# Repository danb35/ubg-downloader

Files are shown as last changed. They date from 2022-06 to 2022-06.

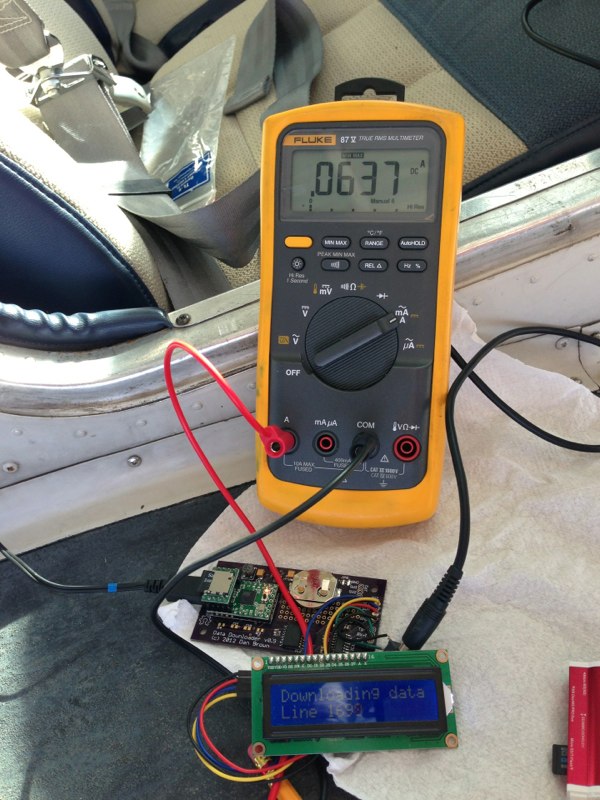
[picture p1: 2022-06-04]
Pictures/IMG_0427.jpg

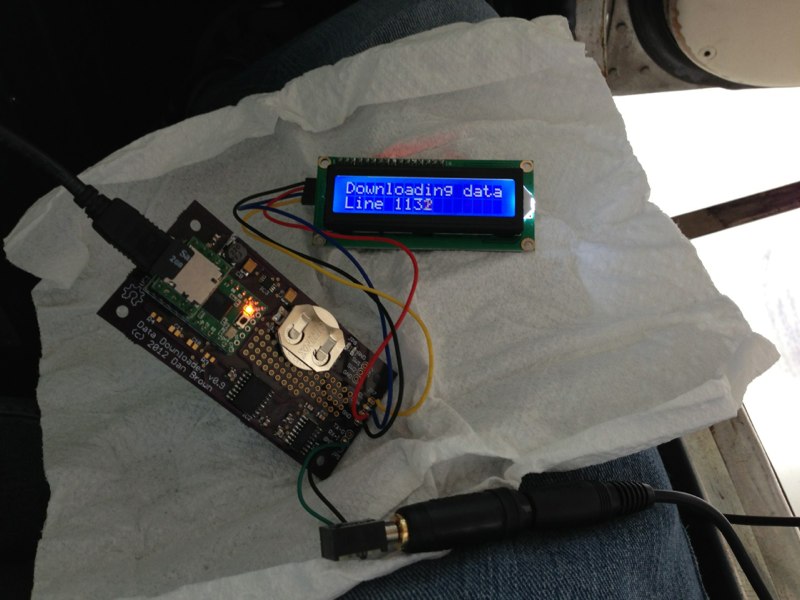
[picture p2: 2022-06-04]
Pictures/IMG_0401.jpg

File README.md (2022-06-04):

# ubg-downloader
Device to download data from EI UBG-16/MUX-8A

# Introduction
This device developed out of a desire to download data from the [Electronics International](https://www.iflyei.com/) [UBG-16](https://www.iflyei.com/product/ubg-16-ultimate-bar-graph/) in my Mooney aircraft.  EI provide (at an extra cost) a serial cable and software you can install on your laptop, but I didn't want to need to drag a laptop out to the plane to download data; I wanted a small, battery-operated device that would download the data onto an SD card.  This device will do that.

# Status
This project is *archived.*  I no longer have the airplane or any of the EI hardware to test with.  The software and hardware documentation are provided here for anyone to use, and to build on if desired, but I won't be able to provide much in the way of support.  Primary development took place in 2012, so my memory may not be too clear about the details.

But with that said, it worked.  Once the clock was set (I never did get around to developing a UI to do that through the device's software itself), it was just a matter of inserting a couple of AA batteries, plugging it into the plane with a 1/8" stereo audio cable, and downloading.  If you can source the parts and assemble the PCB, it should work for you as well.

# Further information

* [Hardware](hardware.md)
* [Software](software.md)
* [Data Format](data-format.md)

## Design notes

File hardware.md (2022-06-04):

# Hardware design
This device is built on a custom printed-circuit board; design files for KiCAD 6.0, schematics, a bill of materials (BOM), and Gerber files are available in the Hardware directory.  You can order PCBs from any PCB fab you like; the most economical are likely to be oshpark.com (US based, three beautiful purple PCBs for $5/square inch) or jlcpcb.com (China-based, good quality, cheap, but shipping can be expensive).  I have no affiliation with either of these vendors.

This PCB uses surface-mount components in order to reduce its size.  If you're careful, you should be able to hand-solder them without difficulty.  JLCPCB (linked above) does offer SMT assembly service, but I haven't verified that all the components I use on this board are available through their service.

The PCB also includes connections for devices that aren't used in the current version of the software.  For example, SW1 and SW2 are intended for pushbutton switches that could be used to, e.g., set certain parameters on the device.  The software doesn't currently use them, though.  Similarly, there's a network of vias below the RTC battery; those are intended for the user to add any desired components, and you'd naturally need to code support for them.

# Components
As noted above, the BOM is in the Hardware directory, but major components of this device include:

* A [Teensy 2.0](https://www.pjrc.com/store/teensy.html) microcontroller board
* A [micro SD Card Adapter](https://www.pjrc.com/store/sd_adaptor.html)
* A [16x2 LCD Display Module](https://www.dfrobot.com/index.php?route=product/product&path=53&product_id=135)

# Background
This circuit and PCB were originally designed in CadSoft EAGLE in 2012.  At that time, that software was available at no charge for certain noncommercial uses.  Since then, licensing has changed and there's no longer a no-cost version of this software.  I've accordingly imported the schematic and PCB layout into KiCAD, which is free and open-source software.

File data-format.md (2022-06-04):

# EI MUX-8A Data Format
 
The [documentation](https://www.iflyei.com/wp-content/uploads/MUX-8A-OIII.pdf) that comes with the MUX-8A data recorder explains quite a bit about the format of the data it downloads to your computer.  However, it leaves a few things unexplained.

First, the connection to your computer is a “dumb” serial connection.  Data only flows one way, from the MUX-8A to your computer, and there’s no way for your computer to control what’s coming or when--the computer just takes, processes, and saves the data dump.

The data dump is initiated using a control switch on your instrument panel.  That switch has three positions: BURST, ON, and DOWNLOAD.  The DOWNLOAD position is momentary--when you release the switch, it returns to the ON position.

When you press (and hold) the switch in the DOWNLOAD position, the MUX-8A sends the word “READY” to your computer.  The software (included with the device) recognizes that, and informs you that it’s ready to download.  You then release the switch, and the data dump begins.

The data is plain ASCII text in CSV format, sent at 9600 bps, 8 data bits, no parity, 1 stop bit (8N1).  I won’t repeat what’s in the manual, but I will describe the difference between the final output of their software and the “raw” download from the device.

This is what the raw download looks like:

```
OBC,157780557
151612429,OFF,1319,0238,0073,0357,1283,0323,1328,0315,0208,0074,0089,0074,0011,0074,0141,0074,GPS,N342065,W0804770,277,132,BUBBA
151612488,OFF,1405,0232,0073,0358,1371,0325,1413,0314,0203,0073,0090,0073,0011,0073,0141,0073,GPS,N342063,W0805043,276,140,BUBBA
151612547,OFF,1410,0236,0074,0362,1376,0333,1418,0321,0199,0074,0089,0073,0009,0073,0142,0073,GPS,N342060,W0805322,277,141,BUBBA
151612606,OFF,1414,0238,0073,0366,1377,0336,1415,0325,0197,0073,0091,0073,0010,0073,0141,0073,GPS,N342058,W0805600,277,139,BUBBA
151612665,OFF,1414,0239,0073,0367,1382,0339,1418,0327,0195,0073,0092,0073,0011,0073,0141,0072,GPS,N342055,W0805878,277,139,BUBBA
[lots snipped]
151987363,OFF,1241,0255,1208,0386,1217,0348,1228,0339,0214,0084,0134,0083,0009,0084,0141,0083,GPS,N372947,W0853511,136,132,BUBBA
Down Load Complete
```

This is identical to the finished download, with a few exceptions:

* The first line, starting with OBC, doesn’t make it into the downloaded file.
* In place of the date/time indications at the beginning of each line, there’s a single large number.
* The downloaded file has the date and time immediately after the “Down Load Complete” indication.

Also note that the downloaded data contains only whole numbers, even if the actual value is fractional.  For example, the 17th field in the data above is the master bus voltage, which is actually 14.1 or 14.2 volts, but is represented as 0141/0142--i.e., it's multiplied by 10.  You'll see something similar with the GPS data.

So here’s the deal: the number in the “OBC” line, and the numbers beginning the rest of the rows, are timestamps.  The EI software converts those, mathematically, to the actual date and time of each of the data sets.  This has to be done in software because the MUX-8A has no idea what the date and time actually are.

So what do the numbers mean?  They’re simply a count of seconds.  My speculation is that it’s the number of seconds since the MUX-8A was first powered on (probably for testing at EI), but EI won’t give further detail on that subject.

The OBC line contains the timestamp for “right now”--the time you begin the download.  The rest of the lines have the timestamp for when they were actually recorded.

Given that information, converting the MUX-8A timestamps to human-readable date and time is fairly straightforward.  UNIX and C treat dates and times as the number of seconds since midnight UTC on 1 Jan 1970.  To convert the MUX-8A values, then, just

* Subtract the number in the OBC line from the current time value (right now, it’s 1343170328).  Call the difference timeSkew.
* Add timeSkew to the timestamps on each line of the downloaded data.
* Using existing time functions, convert that sum back to human-readable date and time.

I hope this information is helpful.

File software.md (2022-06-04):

# Software
This device uses a [Teensy](https://www.pjrc.com/teensy/index.html) microcontroller, an Arduino-compatible device in a smaller physical package.  To use the software, you'll need to compile and flash it to the device, and to do that, you'll need some software:

* The latest version of the [Arduino development environment](https://www.arduino.cc/en/software)
* [Teensyduino](https://www.pjrc.com/teensy/td_download.html), a software add-on for the Arduino software that allows it to compile for the Teensy board.
* The [Teensy Loader](https://www.pjrc.com/teensy/loader.html), the program that actually loads compiled code onto the Teensy board.

With these packages installed, you’ll be able to compile software and load it onto the Teensy board.  You’ll then need to install a couple of libraries to compile and use my code.  Specifically, you’ll need:

* The Time library, which has functions for keeping time, communicating with a Real-Time Clock, and doing math with dates and times

* The SdFat library, which allows the program to create files on SD cards and save data there.

* The [LiquidCrystal_I2C library](http://www.dfrobot.com/image/data/DFR0154/LiquidCrystal_I2Cv1-1.rar), which provides support for the serial LCD.  Please note, there are at least two different libraries with this name.  If you use the LCD module I used, you must use this library.

The first two can be installed directly through the Arduino IDE, but the third must be downloaded and comes as a .zip file.  Unzip it and move the contents into the Arduino/Libraries directory under your home directory, then restart the Arduino software.

The current version of the source code is available in the Software directory.  It appears to work on my prototype hardware, but has not been extensively tested.

# Limitations
The software's in a fairly rough state--I developed it until it did what I needed it to do, then stopped.  Probably the biggest limitation is that there's simply no way, using my software, to set the real-time clock; you'll need to use a different sketch to do that.  Once you've set the clock, it's persistent, and the clock IC used on the PCB holds its accuracy quite well.  But that feature really should have been coded into the software, perhaps using the SW1 and SW2 switches the PCB provides for.

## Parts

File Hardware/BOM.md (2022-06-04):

# Bill of Materials

Below are the parts used in this build, with prices as of 9 December 2012.

| Qty | Description | Unit $ | Ext $ | Source | Comments |
| --- | --- | --- | --- | --- | --- |
| 1 | Teensy 2.0 microcontroller | $16.00 | $16.00 | PJRC ||
| 1 | SD Card Adapter for Teensy | $8.00 | $8.00 | PJRC ||
| 2 | Pins for SD Card Adapter | $0.65 | $1.30 | PJRC ||
| 1 | 16 x 2 LCD display, I2C interface | | | | |
| 1 | 20-pin header pins | $0.72 | $0.72 | Mouser ||
| 1 | Sumida CDRH5D28RH125NP-470MC power inductor | $0.95 | $0.95 | Mouser | No longer available |
| 1 | NCP1402SN50T1G DC-DC converter | $0.86 | $0.86 | Mouser | Discontinued |
| 1 | MBR0520LT1G Schottky diode | $0.34 | $0.34 | Mouser ||
| 1 | 68 µF Tantalum capacitor, 1206 package | $2.50 | $2.50 | Mouser ||
| 1 | 10 µF ceramic capacitor, 0805 package | $0.48 | $0.48 | Mouser ||
| 1 | Toggle switch | $2.04 | $2.04 | Mouser ||
| 1 | Battery holder for 2 AA cells | $0.57 | $0.57 | Mouser ||
| 1 | CR2032 Lithium Battery | $0.61 | $0.61 | Mouser ||
| 1 | CR2032 Lithium battery clip | $0.27 | $0.27 | Mouser ||
| 1 | Switchcraft 35RAPC2AV 3.5mm mono jack | $1.31 | $1.31 | Mouser ||
| 1 | Maxim DS3231 Real-Time Clock IC | $9.59 | $9.59 | Mouser | Long back-order |
| 1 | Maxim MAX232 RS-232 level converter | $1.11 | $1.11 | Mouser | Long back-order |
| 2 | 3.3kΩ resistors, 0805 package | $0.12 | $0.12 | Mouser ||
| 6 | 1 µF ceramic capacitors, 0805 package | $0.16 | $0.96 | Mouser ||

PJRC is pjrc.com.

I have a [shared cart](http://www.mouser.com/ProjectManager/ProjectDetail.aspx?AccessID=a88396852c) for the parts at mouser.com for easier ordering.  Note that as of this time (4 June 2022), some of the parts are discontinued, while others are on a long back-order.  You may want to consider redesigning the circuit to use different parts.

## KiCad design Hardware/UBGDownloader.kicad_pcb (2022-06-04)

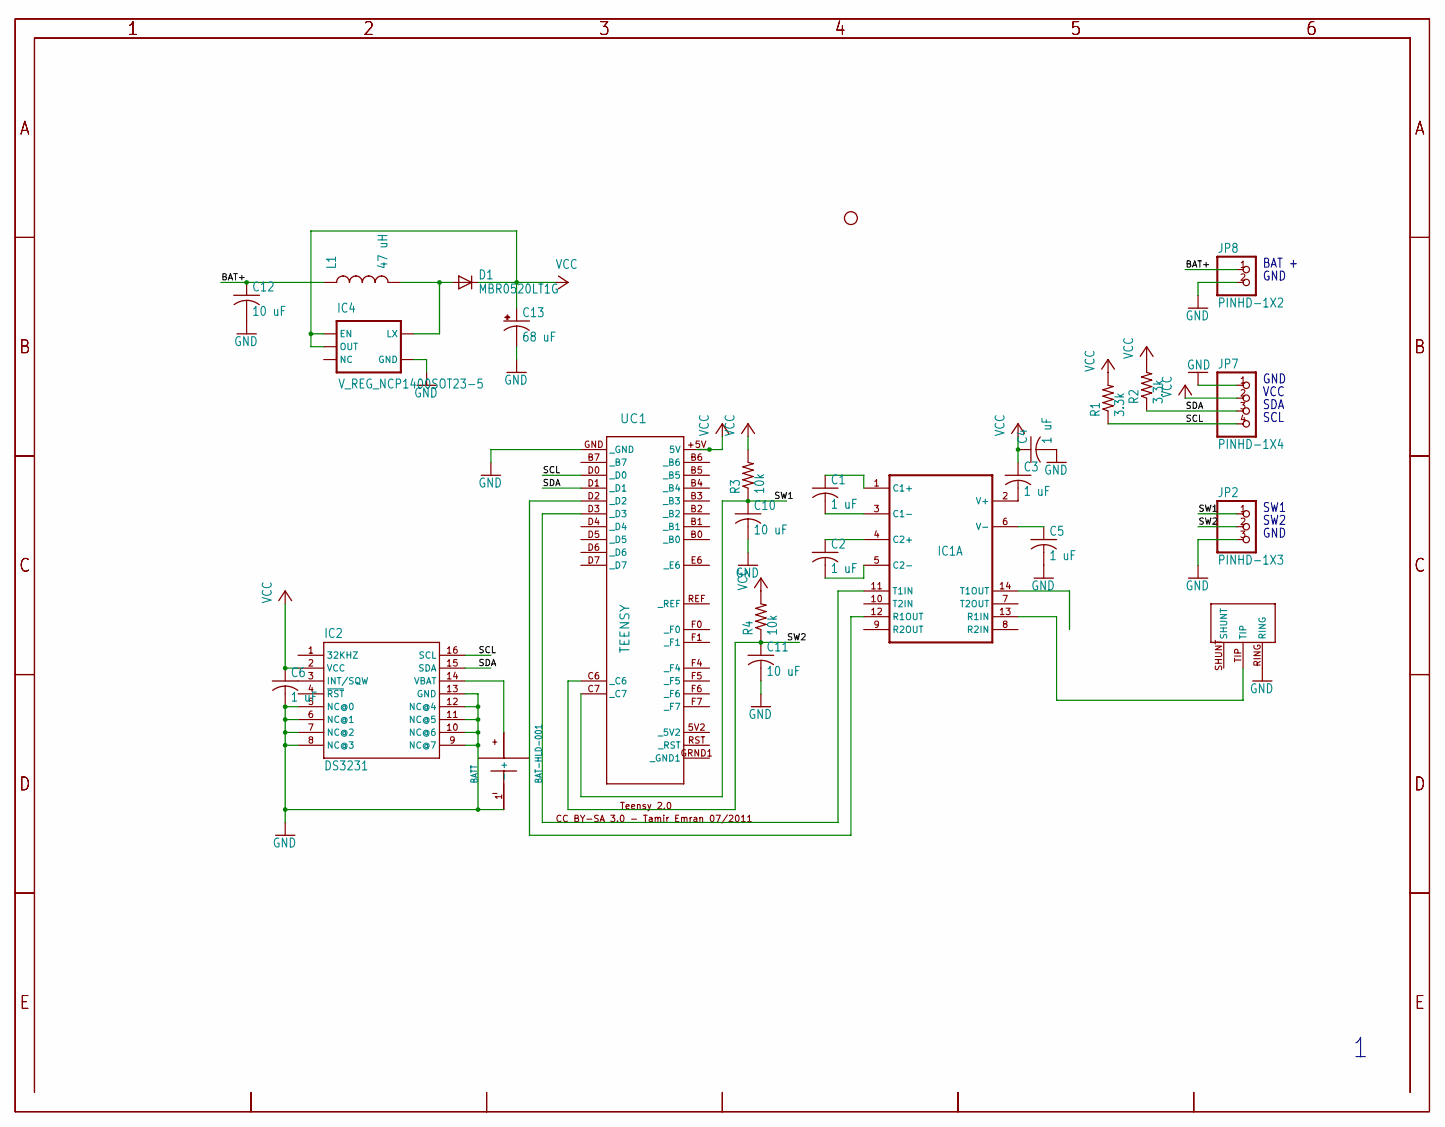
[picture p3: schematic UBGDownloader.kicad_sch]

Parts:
BATT: BAT-HLD-001
C1, C2, C3, C4, C5, C6: 1 uF; C0805K
C10, C11, C12: 10 uF; C0805K
C13: 68 uF; B_3528-21R
D1: MBR0520LT1G; SOD-123_MINI-SMA
IC1: MAX3232SE; SO16
IC2: DS3231; SO-16
IC4: V_REG_NCP1400SOT23-5; SOT23-5
JP2: PINHD-1X3; 1X03
JP5: STAND-OFF
JP7: PINHD-1X4; 1X04
JP8: PINHD-1X2; 1X02
L1: 47 uH; CDRH5D28R
R1, R2: 3.3k; R0805
R3, R4: 10k; R0805
U$3: 35RAPC2AVDEFAULT; 35RAPC2AV
UC1: TEENSY

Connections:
BAT+: C12.1, JP8.1, L1.P$1 (1)
GND: BATT.1 (-), C4.2, C5.2, C6.2, C10.2, C11.2, C12.2, C13.-, IC1.15 (GND), IC2.5 (NC@0), IC2.6 (NC@1), IC2.7 (NC@2), IC2.8 (NC@3), IC2.9 (NC@7), IC2.10 (NC@6), IC2.11 (NC@5), IC2.12 (NC@4), IC2.13 (GND), IC4.4 (GND), JP2.3, JP7.1, JP8.2, U$3.RING, UC1.GND (_GND)
unnamed: BATT.2 (+), BATT.3 (+), IC2.14 (VBAT)
unnamed: C1.2, IC1.3 (C1-)
unnamed: C1.1, IC1.1 (C1+)
unnamed: C2.1, IC1.4 (C2+)
unnamed: C2.2, IC1.5 (C2-)
unnamed: C3.2, IC1.2 (V+)
unnamed: C5.1, IC1.6 (V-)
unnamed: IC1.13 (R1IN), U$3.TIP
unnamed: IC1.11 (T1IN), UC1.D3 (_D3)
unnamed: IC1.12 (R1OUT), UC1.D2 (_D2)
unnamed: D1.A, IC4.5 (LX), L1.P$2 (2)
SCL: IC2.16 (SCL), JP7.4, R1.1, UC1.D0 (_D0)
SDA: IC2.15 (SDA), JP7.3, R2.1, UC1.D1 (_D1)
SW1: C10.1, JP2.1, R3.1, UC1.C7 (_C7)
SW2: C11.1, JP2.2, R4.1, UC1.C6 (_C6)
VCC: C3.1, C4.1, C6.1, C13.+, D1.C, IC1.16 (VCC), IC2.2 (VCC), IC4.1 (EN), IC4.2 (OUT), JP7.2, R1.2, R2.2, R3.2, R4.2, UC1.+5V (5V)

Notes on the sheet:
SW2
GND
SDA
VCC
SCL
BAT +
SW1

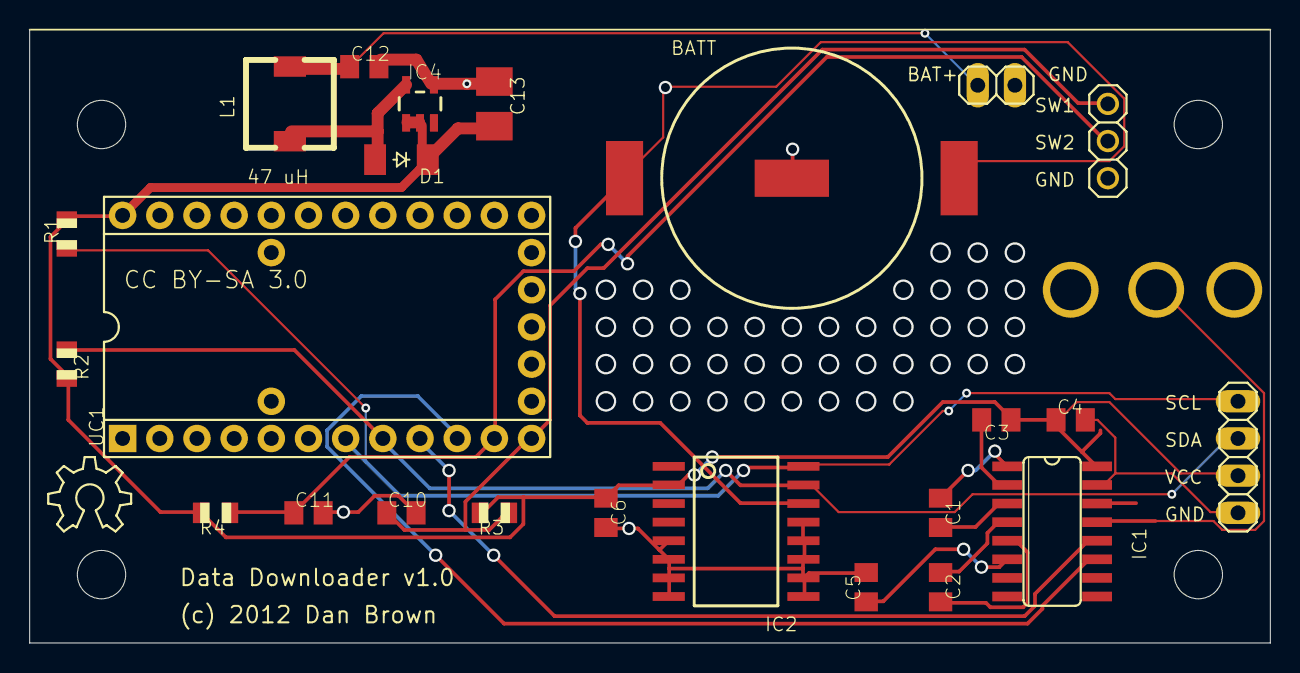
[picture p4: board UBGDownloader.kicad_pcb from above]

Board: 2 copper layers, 84.8 x 41.9 mm, 30 parts (1 on the bottom side), 18 nets.

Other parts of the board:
JP3, JP4, JP6: STAND-OFF
U$2: OSHW_6X200_NOTEXT

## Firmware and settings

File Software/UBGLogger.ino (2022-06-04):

/*
 * Data Logger
 * Reads data from EI UBG-16, reformats date, and saves to microSD Card
 * Uses Serial read line code from Nick Gammon, see
 * http://gammon.com.au/serial
 *
 * Copyright 2012 Daniel C. Brown
 * Released under the GNU General Public License, v3
 * See the file COPYING for license agreement or
 * http://www.gnu.org/licenses/gpl.html
 *
 */

#include <Wire.h>
#include <Time.h>
#include <DS1307RTC.h>
#include <SdFat.h>
#include <LiquidCrystal_I2C.h>

const unsigned int MAX_INPUT = 160;
const int SdChipSelect = 0;
unsigned long muxTime = 0;
unsigned long timeSkew = 0;
unsigned long dataTime = 0;
byte ledPin = 11;
byte i;
boolean ready = false; 
char logFile[13];
char dataTimeString[20];
int line = 0;
time_t t;
int lastMinute;

HardwareSerial Uart = HardwareSerial();
LiquidCrystal_I2C lcd(0x27,16,2);  // set the LCD address to 0x27 for a 16 chars and 2 line display
SdFat sd;
SdFile myFile;

void setup()
{
  Serial.begin(38400);
  Uart.begin(9600);
  lcd.init();
  lcd.backlight();
  lcd.clear();
  lcd.setCursor(0,0);
  setSyncProvider(RTC.get); // the function to get the time from the RTC
  pinMode(ledPin, OUTPUT);
  delay(1000);
  if (!sd.init(SPI_FULL_SPEED, SdChipSelect))
  {
    lcd.print("SD Init failed!");
  }
  else
  {
    lcd.setCursor(1,0);
    lcd.print("Begin download");
    t = now();
    sprintf(dataTimeString,"%.2d/%.2d/%.4d %.2d:%.2d",
    month(t), day(t), year(t), hour(t), minute(t)); 
    lcd.setCursor(0,1);
    lcd.print(dataTimeString);
    lastMinute = minute(t);
  }
}


void process_data (char *data)
{
  // Test for content - READY, OBC, Down, or other
  if ((strncmp(data, "OBC", 3) == 0) && (ready == true)) { // Process OBC and set timeSkew
    char muxTimeString [12];
    if (data[3] == ',') { // Read the timestamp from the MUX
      i = 4;
      do {
        muxTimeString [i - 4] = data [i];
        muxTimeString [i - 3] = 0;
        i++;
      } 
      while ((data [i] != 0) && (i < 15));
    }
    muxTime = atol(muxTimeString);
    timeSkew = now() - muxTime; // Compute difference between MUX timestamp and actual time
    lcd.clear();
    lcd.setCursor(0,0);
    lcd.print("Downloading data");
    lcd.setCursor(0,1);
    lcd.print("Line");  
  } 
  else if ((strncmp(data, "READY", 5) == 0) && (ready == false)) { // Create logfile, annunciate Ready
    if (createLogFile())
    {
      digitalWrite(ledPin, HIGH);
      lcd.clear();
      lcd.setCursor(0,0);
      lcd.print("Ready to download");
      line = 0;
      ready = true;
    }
  }
  else if ((strncmp(data, "READY", 5) == 0) && (ready == true)) { // Ignore the line
  }
  else if ((strncmp(data, "Down", 4) == 0) && (ready == true)) { // Download complete - close file
    if (data[10] == 'C') {
      myFile.print("Download Completed ");
    }
    else if (data[10] == 'I') {
      myFile.print("Download Interrupted ");
    }
    else {
      myFile.print(data);
      myFile.print(" ");
    }
    t = now();
    sprintf(dataTimeString,"%.2d/%.2d/%.4d %.2d:%.2d:%.2d",
    month(t), day(t), year(t), hour(t), minute(t), second(t));
    myFile.println(dataTimeString);
    myFile.timestamp(T_WRITE, year(t), month(t), day(t), hour(t), minute(t), second(t));
    myFile.close();
    digitalWrite(ledPin, LOW);
    lcd.clear();
    lcd.setCursor(4,0);
    lcd.print("Download");
    lcd.setCursor(4,1);
    lcd.print("Complete");
    ready = false;
  }
  else if (ready == true) // process and log data
  { 
    i = 0;
    while (data [i] != ',') // first field is the time stamp
    {
      dataTimeString[i] = data[i];
      i++;
    }
    dataTimeString[i] = 0;
    dataTime = atol(dataTimeString) + timeSkew; // Adjust dataTime for time skew
    time_t t = dataTime;
    sprintf(dataTimeString,"%.2d/%.2d/%.4d %.2d:%.2d:%.2d",
    month(t), day(t), year(t), hour(t), minute(t), second(t));
    myFile.print(dataTimeString);
    myFile.println((char *)&data[i]); // print out the rest of the input line, from the first comma on
    line++;
    lcd.setCursor(5,1);
    lcd.print(line);
  } 
}  // end of process_data

boolean createLogFile()

/* Creates /logs/ directory, if not already present, and log file
 * file name is yymmddnn.csv
 * yy = 2-digit year
 * mm = 2-digit month
 * dd = 2-digit day
 * nn = first unused number from 00-99
 * Requires system clock to be set to year >= 2000
 */

{
  if (!sd.exists("/logs/"))
  {
    if (!sd.mkdir("/logs"))
    {
      lcd.clear();
      lcd.setCursor(0,0);
      lcd.print("Couldn't mkdir!");
      return false;
    }
  } // create logs directory, if not already present
  if  (!sd.chdir("/logs"))
  {
    lcd.clear();
    lcd.setCursor(0,0);
    lcd.print("Couldn't chdir!");
    return false;
  }
  time_t t = now();
  int yr = year(t) - 2000;
  sprintf(logFile,"%.2d%.2d%.2d00.csv",
  yr, month(t), day(t));
  for (i = 0; i < 100; i++)
  {
    logFile[6] = i/10 + '0';
    logFile[7] = i%10 + '0';
    if (sd.exists(logFile))
    {
      continue;
    }
    if(myFile.open(logFile,O_RDWR | O_CREAT | O_AT_END)) {
      t = now();
      myFile.timestamp(T_CREATE, year(t), month(t), day(t), hour(t), minute(t), second(t));
      lcd.clear();
      lcd.setCursor(0,0);
      lcd.print("Downloading to:");
      lcd.setCursor(0,1);
      lcd.print(logFile);
      delay(300);
      return true;
    }
    else
    {
      lcd.setCursor(0,0);
      lcd.print(logFile);
      lcd.setCursor(0,1);
      lcd.print("Not Created!");
      return false;
    }
    break;
  }
}

void loop()
{
  static char input_line [MAX_INPUT];
  static unsigned int input_pos = 0;

  if (ready == false)
  {
    t = now();
    if (minute(t) != lastMinute)
    {
      sprintf(dataTimeString,"%.2d/%.2d/%.4d %.2d:%.2d",
      month(t), day(t), year(t), hour(t), minute(t)); 
      lcd.setCursor(0,1);
      lcd.print(dataTimeString);
      lastMinute = minute(t);
    }
  }

  if (Uart.available () > 0) 
  {
    char inByte = Uart.read ();
    switch (inByte)
    {
    case '\n':   // end of text
      input_line [input_pos] = 0;  // terminating null byte
      // terminator reached! process input_line here ...
      process_data (input_line);
      // reset buffer for next time
      input_pos = 0;  
      break;

    case '\r':   // discard carriage return
      break;

    default:
      // keep adding if not full ... allow for terminating null byte
      if (input_pos < (MAX_INPUT - 1))
        input_line [input_pos++] = inByte;
      break;

    }  // end of switch

  }  // end of incoming data

}  // end of loop

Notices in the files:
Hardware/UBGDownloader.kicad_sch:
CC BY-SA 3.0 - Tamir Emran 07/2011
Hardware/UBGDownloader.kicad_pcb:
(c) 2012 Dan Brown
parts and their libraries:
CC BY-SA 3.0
